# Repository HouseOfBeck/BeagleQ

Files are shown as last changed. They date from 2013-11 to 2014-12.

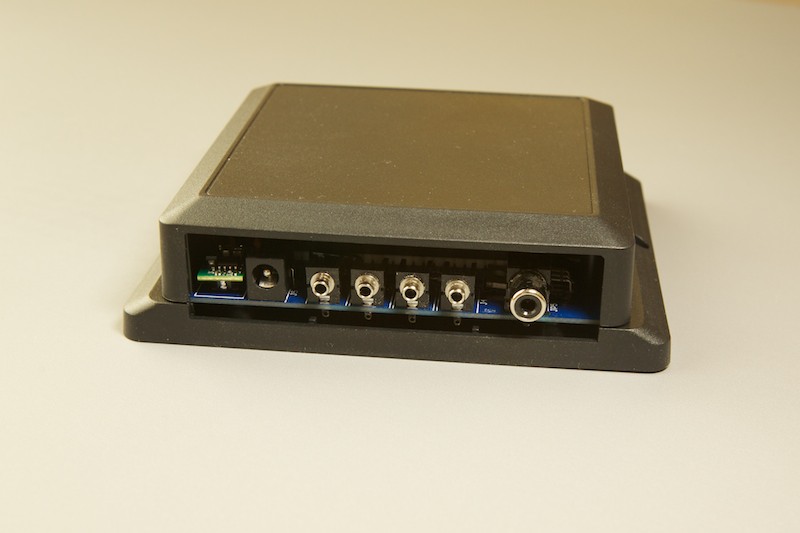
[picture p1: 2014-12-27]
images/beagleq-6.jpg

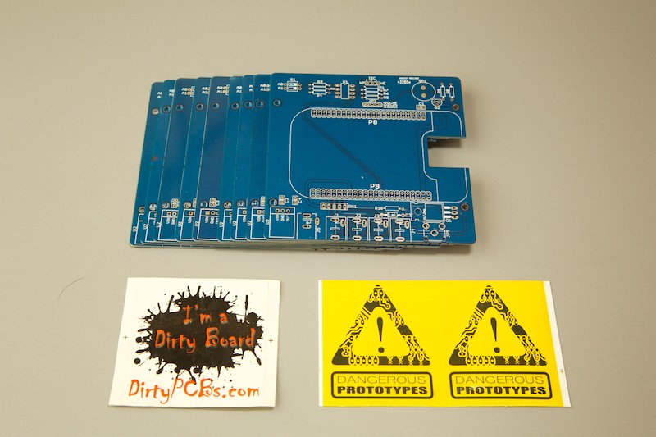
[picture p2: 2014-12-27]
images/beagleq-1.jpg

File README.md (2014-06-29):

BeagleQ bbq controller based on the beaglebone black platform.

Big changes for new Version 3.  New Version 3 board. Built in DC power converter. New form factor to fit off the shelf case.

The BeagleQ is a wifi enabled wireless intelligent bbq smoker controller. This device is designed to control a fan connected to the smoker's input vent/damper. Using a temperature probe placed in the pit the controller can read the pit temperature and then adjust the fan speed to act as a bellows to cause the coals to heat up and raise the pit temperature. The fan shuts down when the desired temperature is reached. By continually monitoring the temperature and adjusting the fan speed the controller can insure a smooth low and slow cook.

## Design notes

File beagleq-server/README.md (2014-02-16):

My first cut at node.js server. It requires the websocket 'ws' module.

Still a bit rough around the edges but I wanted to get something out.

It has a simulator mode where it will read the input file "cook.log" to use as input
temperatures. I use this for testing the PID and other functions.

For real use run start it up first then pull up the web client.

./beagleq-server
Parsing probes.json
Found probe ... ET-73
0.0002284143823
0.0002373151289
1.249333734e-7
R8: 9960
R9: 9950
R10: 9920
R11: 9995
Server running on port: 8086

<now start client in web browser>

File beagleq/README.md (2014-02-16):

This is the beagleq client.

Copy this entire directory into /usr/share/bone101/

Next, make sure the server is running.

then load the page in a web browser

http://your.beagle.address/beagleq/

If everything is working correctly you will see a connect message in the status pane.
Then temperatures will start appearing in the temperature pane and the gauges will 
indicate the temps. On the "chart" tab a plot will begin to appear.

The "test" tab is my play area. It will eventually go away.

The "about" tab will have the correct information for your beaglebone. The cape
eeprom data is static and not yet dynamic. It's on my list to fix.

Anyone with web frontend development skills is encouraged to help out.
In particular, I want to eliminate the google gauges in favor of something
like Highcharts so that the it can run without an internet connection.

Also, I need to add more tabs to tune the PID and manage output files.

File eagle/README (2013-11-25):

I've had a batch of these boards build at OSH Park and they work fine.
There's one minor issue. One mounting hole on the headphone/RCA jacks is a wee bit to small.
A little touch of the dremel on the pin and it fits in just fine.

Functionally I'm happy with this board and will use it as the basis for my
software developement.

You can order these boards from OSH Park here

http://www.oshpark.com/shared_projects/zo1bDKMN

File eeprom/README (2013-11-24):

This directory contains all the files needed to setup the eeprom on the
cape and the device tree overlays on the BBB.

These are the get started quick instructions. Details on customizing these
files will come later.

Write the eeprom image

1) Make sure the WP/WE jumper is in the WE position
2) The A0/A1 jumpers determine the cape i2c bus address. The two jumpers give you a range 
   from 0-3. The A2 address is fixed in hardware. Using the value set using the 
   A0/A1 jumpers plus 4 (ie 54-57) you can write the eeprom image using this command

   cat beagleq-cape-2.0.eeprom > /sys/bus/i2c/drivers/at24/1-005x/eeprom 

   If you want to check that it worked you can do a 

   cat /sys/devices/bone_capemgr.*/slots

3) Install the device tree overlay

   cp BeagleQ-02-00A0.dtbo /lib/firmware/. 

4) Reboot the BBB and check that the cape is there

   root@bbb-w:~# cat /sys/devices/bone_capemgr.*/slots
   0: 54:P---L BeagleQ-Cape,00A0,HouseOfBeck,BeagleQ-02
   1: 55:PF--- 
   2: 56:PF--- 
   3: 57:PF--- 
   4: ff:P-O-L Bone-LT-eMMC-2G,00A0,Texas Instrument,BB-BONE-EMMC-2G
   5: ff:P-O-L Bone-Black-HDMI,00A0,Texas Instrument,BB-BONELT-HDMI

Write calibartion data to eeprom

1) Carefully measure the values of R8, R9, R10, R11 during construction of the cape.
2) Edit the write_calibartion.py program to include your measured values. My values
   for this line were R8=9960, R9=9950,R10=9920,R11=9995

   out_array = array('l', [9960,9950,9920,9995])
3) Now write those values to the eeprom. The program writes the values and then
   reads then back out to verify.

   root@bbb-w:~/firmware# python write_calibration.py 
   array('l', [9960, 9950, 9920, 9995])

4) Move the WP/WE enable jumper to WP

Now go to the demo directory and see it work.

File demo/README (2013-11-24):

This simple python code uses the Adafruit BBIO library. First install it on
your BBB using the instructions found here

http://learn.adafruit.com/setting-up-io-python-library-on-beaglebone-black

You can then run this demo to exercise all the functions on the cape.

root@bbb-w:~/checkout# python demo.py

Reading calibration data from eeprom ... 

9960
9950
9920
9995

Reading ADC pins ...

P9_33 P9_38 P9_37 P9_40

1782.0 8.0 2.0 1637.0
1785.0 0.0 1.0 1614.0
1785.0 1.0 5.0 1624.0
1785.0 1.0 6.0 1656.0
1783.0 3.0 4.0 1664.0
1782.0 2.0 1.0 1664.0
1782.0 2.0 0.0 1661.0
1783.0 3.0 4.0 1643.0
1784.0 1.0 1.0 1661.0
1783.0 0.0 0.0 1628.0

Setting up PWM 4kHz on P9_16...buzzer test
Tearing down... Done...buzzer test
Setting up PWM...
Fan...100% duty cycle
Fan...75% duty cycle
Fan...50% duty cycle
Fan...25% duty cycle
Stopping...
Tearing down...
Done

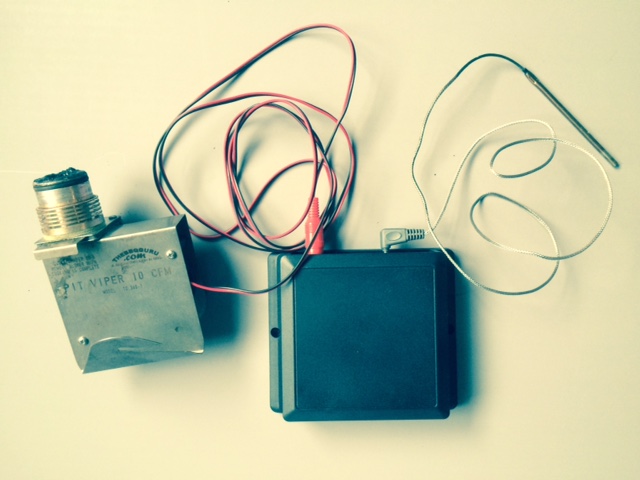
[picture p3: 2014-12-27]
images/beagleq-connect.jpg

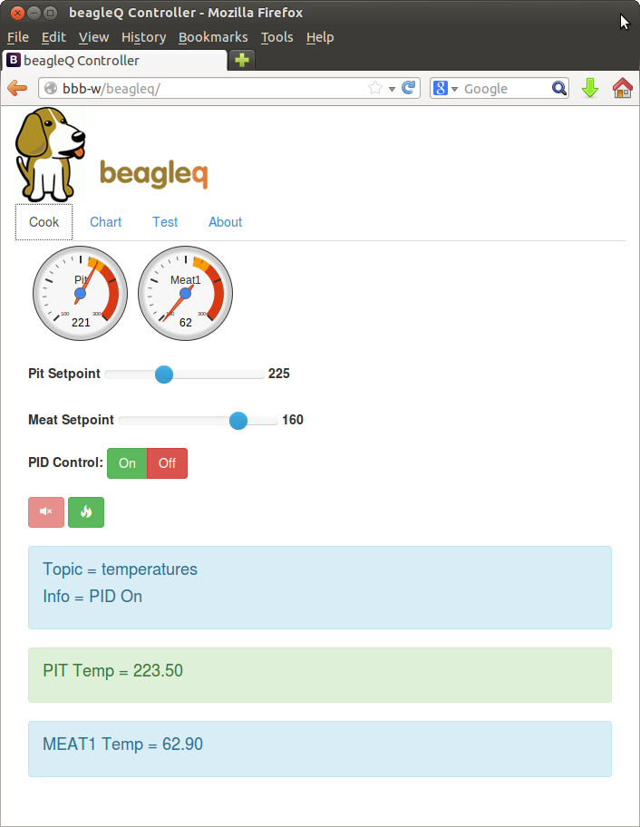
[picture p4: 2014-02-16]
images/beagleq-screen-cook.png

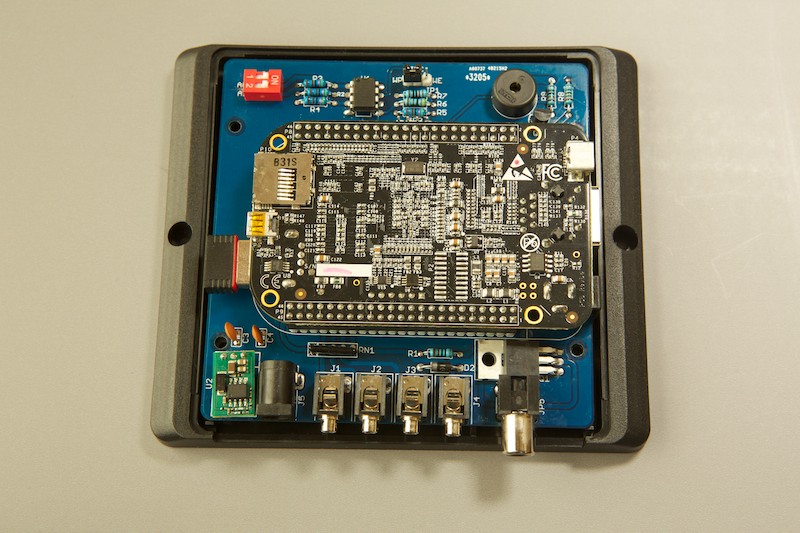
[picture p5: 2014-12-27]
images/beagleq-5.jpg

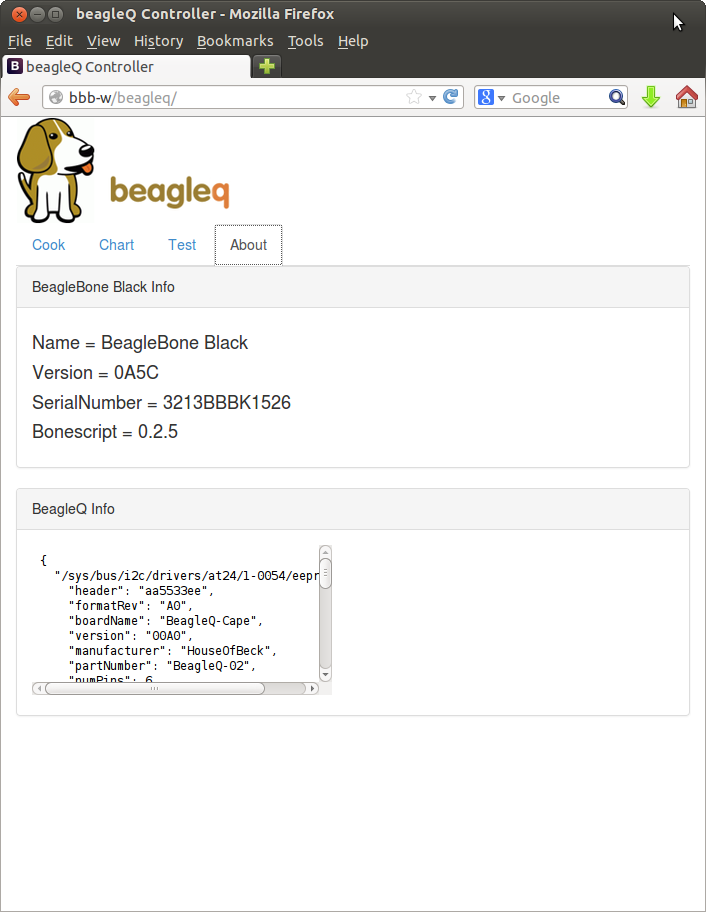
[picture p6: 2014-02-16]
images/beagleq-screen-about.png

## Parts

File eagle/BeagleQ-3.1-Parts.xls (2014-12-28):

Digi-Key Part Number | Manufacturer | Manufacturer Part Number | Customer Reference | Quantity 1 | Quantity 2 | Quantity 3 | Mfg Std Lead Time | Description | Comments | RoHS Status | Lead Free Status | REACH Status
PJRAN1X1U01X-ND | SWITCHCRAFT INC | PJRAN1X1U01X | JP5 FAN PLUG | 1 | 0 | 0 | 6 Weeks | CONN JACK 1POS R/A PHONO BLACK |  | RoHS Compliant | Lead free | Unaffected Dec-2012
445-2525-1-ND | TDK CORPORATION (VA) | PS1240P02BT | SP1 BUZZER | 1 | 0 | 0 | 12 Weeks | BUZZER PIEZO 4KHZ 12.2MM PC MNT | Alternate Packaging Exists | RoHS Compliant | Lead free | Unaffected Apr-2011
CP-2508N-ND | CUI INC | MJ-2508N | J1-J4 PROBE PLUGS | 4 | 0 | 0 | 11 Weeks | CONN AUDIO JACK 2.5MM MONO |  | RoHS Compliant | Lead free | Unaffected Oct-2010
CSC10KC-ND | VISHAY DALE | CSC05A0110K0GEK | RN1 | 1 | 0 | 0 | 22 Weeks | RES ARRAY 10K OHM 4 RES 5SIP |  | RoHS Compliant | Lead free | Unaffected Dec-2011
IRLB8721PBF-ND | INTERNATIONAL RECTIFIER | IRLB8721PBF | Q1 | 1 | 0 | 0 | 11 Weeks | MOSFET N-CH 30V 62A TO-220AB |  | RoHS Compliant | Lead free | Unaffected Dec-2013
BC2665CT-ND | VISHAY BC COMPONENTS (VA) | K104K10X7RF5UH5 | C1, C3, C4 | 3 | 0 | 0 | 6 Weeks | CAP CER 0.1UF 50V 10% RADIAL | Alternate Packaging Exists | RoHS Compliant | Lead free | Unaffected Jun-2011
641-1310-1-ND | COMCHIP TECHNOLOGY (VA) | 1N4001-G | D2 | 1 | 0 | 0 | 10 Weeks | DIODE GEN PURPOSE 50V 1A DO41 | Alternate Packaging Exists | RoHS Compliant | Lead free | Unaffected Dec-2013
24FC256-I/P-ND | MICROCHIP TECHNOLOGY | 24FC256-I/P | U1 EEPROM | 1 | 0 | 0 | 14 Weeks | IC EEPROM 256KBIT 1MHZ 8DIP |  | RoHS Compliant | Lead free | Unaffected Dec-2013
1.00KXBK-ND | YAGEO | MFR-25FBF52-1K | R1, R8, R9 | 3 | 0 | 0 | 14 Weeks | RES 1K OHM 1/4W 1% AXIAL | Alternate Packaging Exists | RoHS Compliant | Lead free | Unaffected Jun-2011
S4.7KCACT-ND | STACKPOLE ELECTRONICS INC (VA) | RNMF14FTC4K70 | R2-R6 | 5 | 0 | 0 | 12 Weeks | RES 4.7K OHM 1/4W 1% AXIAL | Alternate Packaging Exists | RoHS Compliant | Lead free | Unaffected Jun-2014
CP-102A-ND | CUI INC | PJ-102A | J5 POWER PLUG | 1 | 0 | 0 | 11 Weeks | CONN JACK POWER 2.1MM PCB |  | RoHS Compliant | Lead free | Unaffected Oct-2010
952-2330-ND | HARWIN INC | M20-9763646 | HEADER, DOUBLE | 2 | 0 | 0 | 8 Weeks | 2X36 POS DIL VERT PIN HDR |  | RoHS Compliant | Lead free | Unaffected Jun-2014
929400E-01-36-ND | 3M | 929400-01-36-RK | HEADER, SINGLE ROW | 1 | 0 | 0 | 2 Weeks | CONN HEADER .100 SNGL STR 36POS |  | RoHS Compliant | Lead free | Not Available
PN2222ATFCT-ND | FAIRCHILD SEMICONDUCTOR (VA) | PN2222ATF | Q2 SPEAKER TRANSISTOR | 1 | 0 | 0 | 7 Weeks | TRANS NPN 40V 1A TO-92 | Alternate Packaging Exists | RoHS Compliant | Lead free | Unaffected Dec-2013
811-2692-ND | MURATA POWER SOLUTIONS INC | OKI-78SR-5/1.5-W36H-C | DC-DC CONVERTER | 1 | 0 | 0 | 10 Weeks | DC/DC CONVERTER 5V 8W |  | RoHS Compliant | Lead free | Not Available
RNF14FTD10K0CT-ND | STACKPOLE ELECTRONICS INC (VA) | RNF14FTD10K0 | R7 | 1 | 0 | 0 | 12 Weeks | RES 10K OHM 1/4W 1% AXIAL | Alternate Packaging Exists | RoHS Compliant | Lead free | Unaffected Jun-2014
CT2082-ND | CTS ELECTROCOMPONENTS | 208-2 | S1 | 1 | 0 | 0 | 5 Weeks | SWITCH TIN CONT 2 SEC 50V |  | RoHS Compliant | Lead free | Unaffected Jul-2011

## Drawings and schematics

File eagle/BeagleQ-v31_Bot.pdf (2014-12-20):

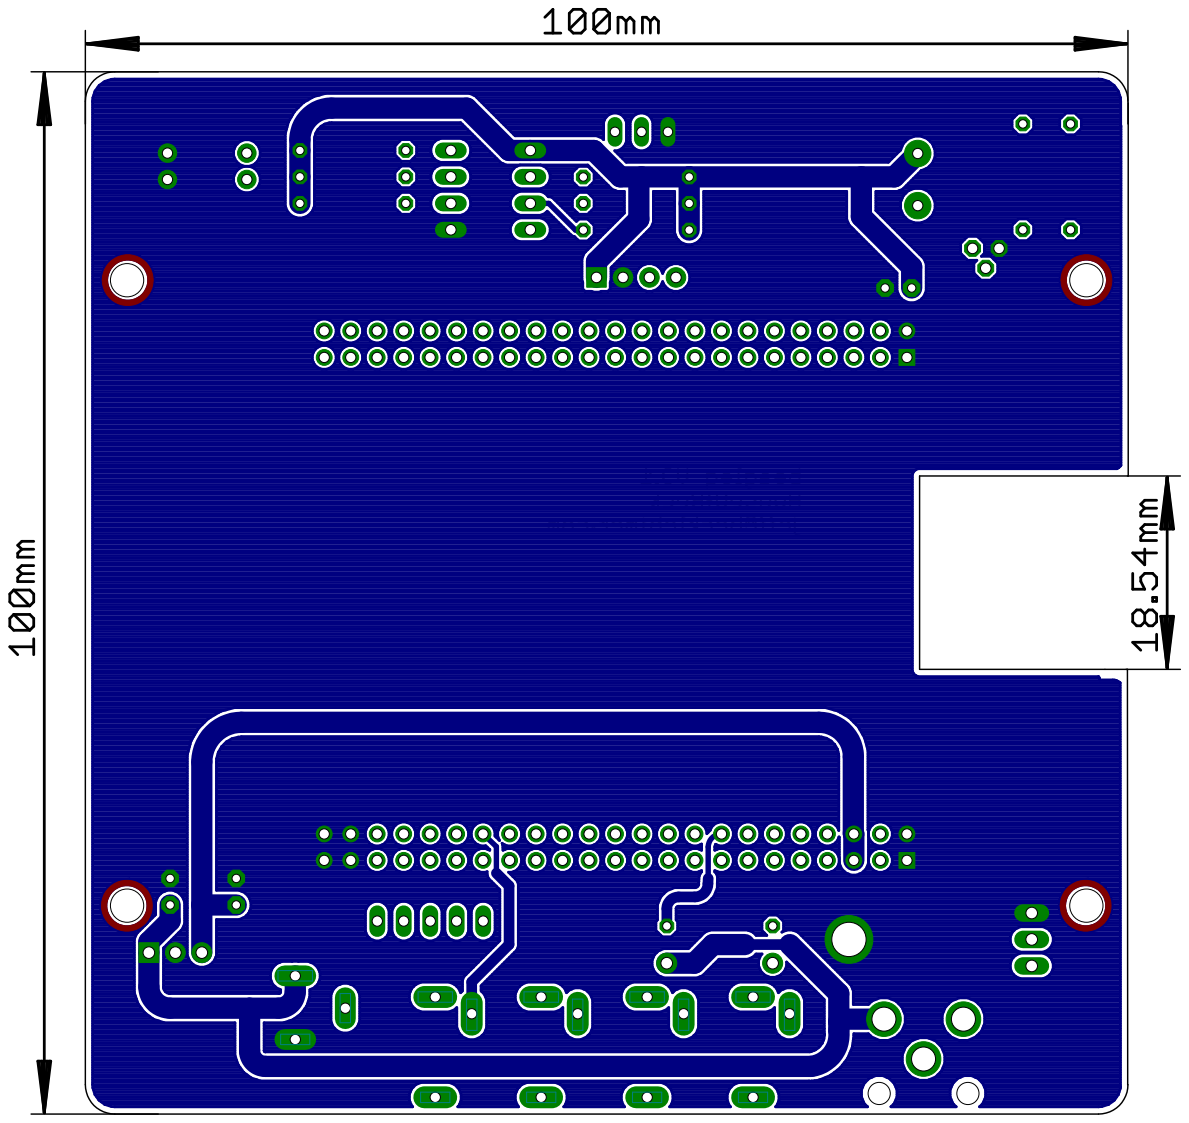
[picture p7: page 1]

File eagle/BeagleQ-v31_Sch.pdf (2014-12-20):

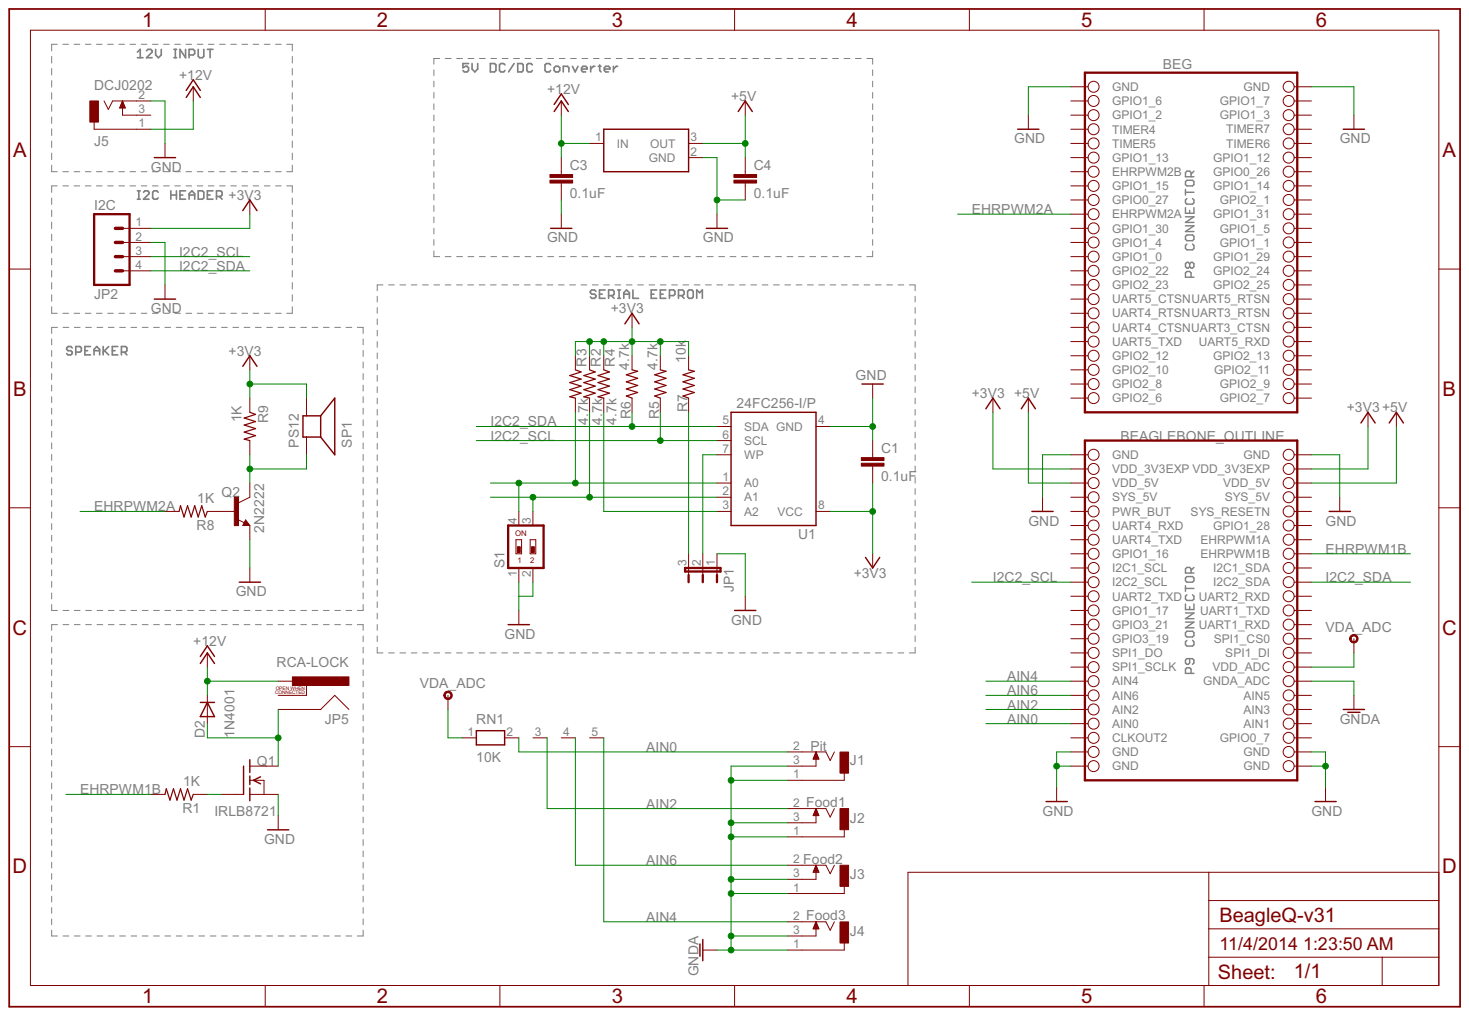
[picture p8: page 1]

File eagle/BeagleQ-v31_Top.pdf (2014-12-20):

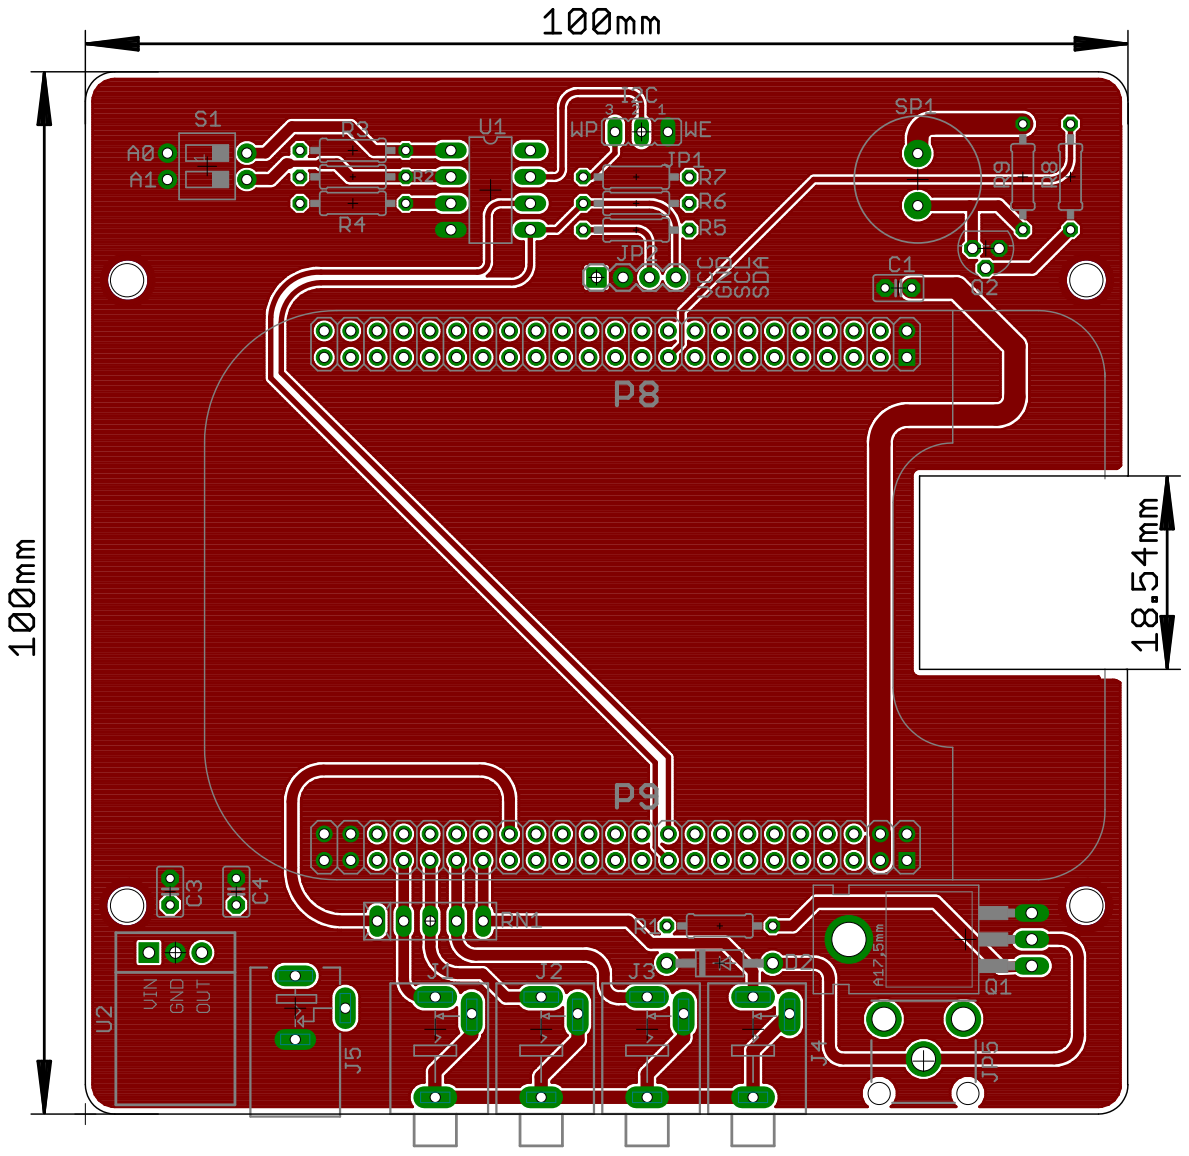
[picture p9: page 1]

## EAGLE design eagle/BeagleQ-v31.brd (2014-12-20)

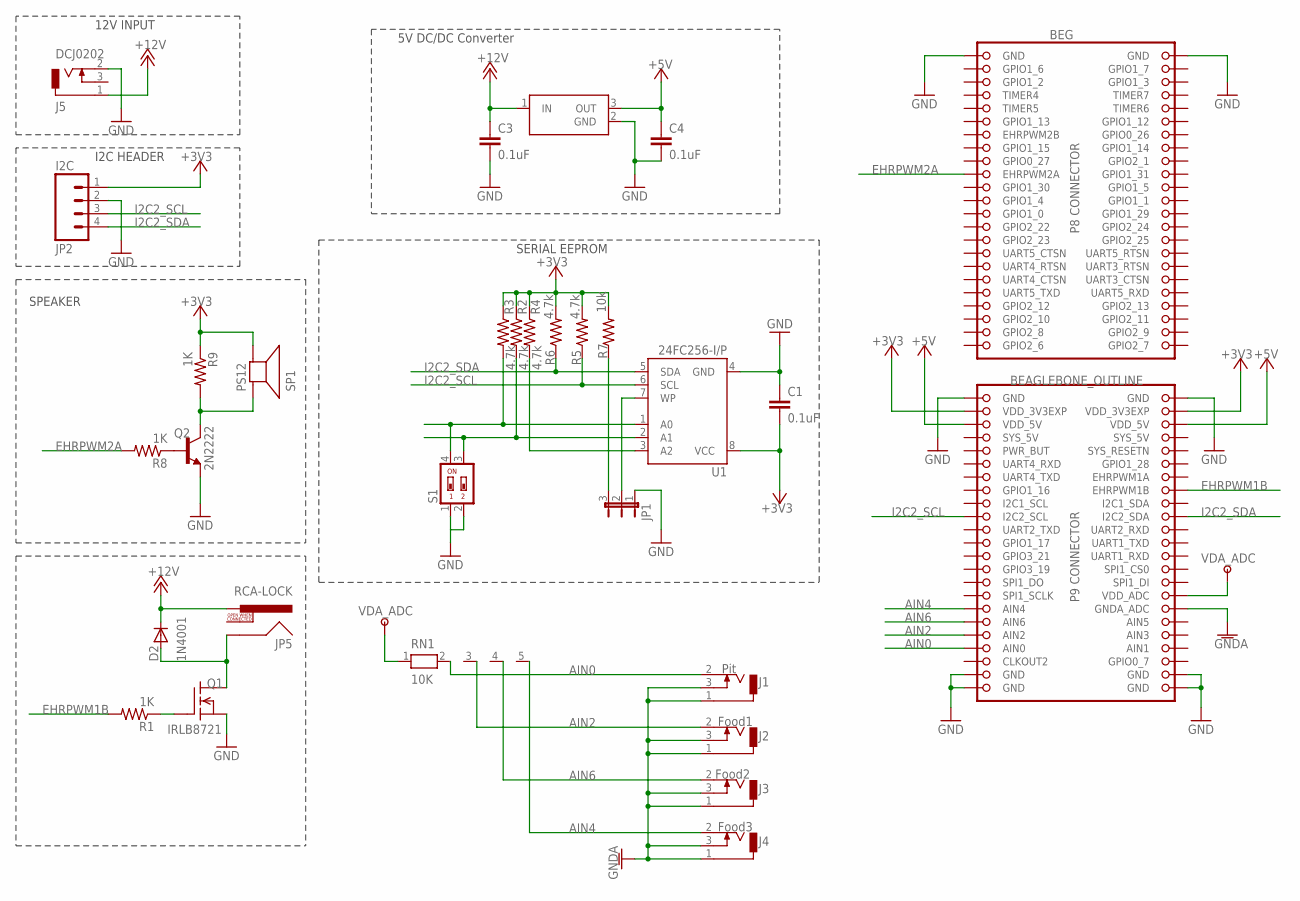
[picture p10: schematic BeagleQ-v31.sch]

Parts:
BEG: BEAGLEBONE_OUTLINE; BEAGLEBONE_SHIELD
C1, C3, C4: 0.1uF; C2.5-2
D2: 1N4001; DO41-10
J1: Pit; MJ-2508N
J2: Food1; MJ-2508N
J3: Food2; MJ-2508N
J4: Food3; MJ-2508N
J5: DCJ0202
JP1: WP; JP2
JP2: I2C; 1X04
JP5: RCA-LOCK; RCA_LOCK
Q1: IRLB8721; TO220
Q2: 2N2222; TO-92
R1, R8, R9: 1K; 0207/10
R2, R3, R4, R5, R6: 4.7k; 0207/10
R7: 10k; 0207/10
RN1: 10K; RN-5
S1: SWS002; SMS-002
SP1: PS12
U1: 24FC256-I/P; DIL08
U2: OKI-78SRHZNTL; OKI-78SR-HZNTL

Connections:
+3V3: BEG.49 (VDD_3V3EXP), BEG.50 (VDD_3V3EXP), C1.2, JP2.1, R2.1, R3.1, R4.1, R5.2, R6.2, R7.2, R9.1, SP1.P$2 (-), U1.8 (VCC)
+5V: BEG.51 (VDD_5V), BEG.52 (VDD_5V), C4.1, U2.3 (OUT)
+12V: C3.1, D2.C, J5.1, JP5.PIN, U2.1 (IN)
AIN0: BEG.85 (AIN0), J1.2, RN1.2
AIN2: BEG.83 (AIN2), J2.2, RN1.3
AIN4: BEG.79 (AIN4), J4.2, RN1.5
AIN6: BEG.81 (AIN6), J3.2, RN1.4
BLOWER_L: D2.A, JP5.SHELL, Q1.2 (D)
EHRPWM1B: BEG.62 (EHRPWM1B), R1.2
EHRPWM2A: BEG.19 (EHRPWM2A), R8.2
GND: BEG.1 (GND), BEG.2 (GND), BEG.47 (GND), BEG.48 (GND), BEG.89 (GND), BEG.90 (GND), BEG.91 (GND), BEG.92 (GND), C1.1, C3.2, C4.2, J5.2 (3), JP1.1, JP2.2, Q1.3 (S), Q1.4 (S), Q2.1 (E), S1.1, S1.2, U1.4 (GND), U2.2 (GND)
GNDA: BEG.80 (GNDA_ADC), J1.1, J1.3, J2.1, J2.3, J3.1, J3.3, J4.1, J4.3
I2C2_SCL: BEG.65 (I2C2_SCL), JP2.3, R5.1, U1.6 (SCL)
I2C2_SDA: BEG.66 (I2C2_SDA), JP2.4, R6.1, U1.5 (SDA)
unnamed: R2.2, S1.3, U1.2 (A1)
unnamed: R3.2, S1.4, U1.1 (A0)
unnamed: JP1.2, U1.7 (WP)
unnamed: Q1.1 (G), R1.1
unnamed: JP1.3, R7.1
unnamed: R4.2, U1.3 (A2)
unnamed: Q2.2 (B), R8.1
unnamed: Q2.3 (C), R9.2, SP1.P$1 (+)
SYS_5V: BEG.53 (SYS_5V)
VDA_ADC: BEG.78 (VDD_ADC), RN1.1

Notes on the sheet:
12V INPUT
I2C HEADER
SERIAL EEPROM
5V DC/DC Converter
SPEAKER

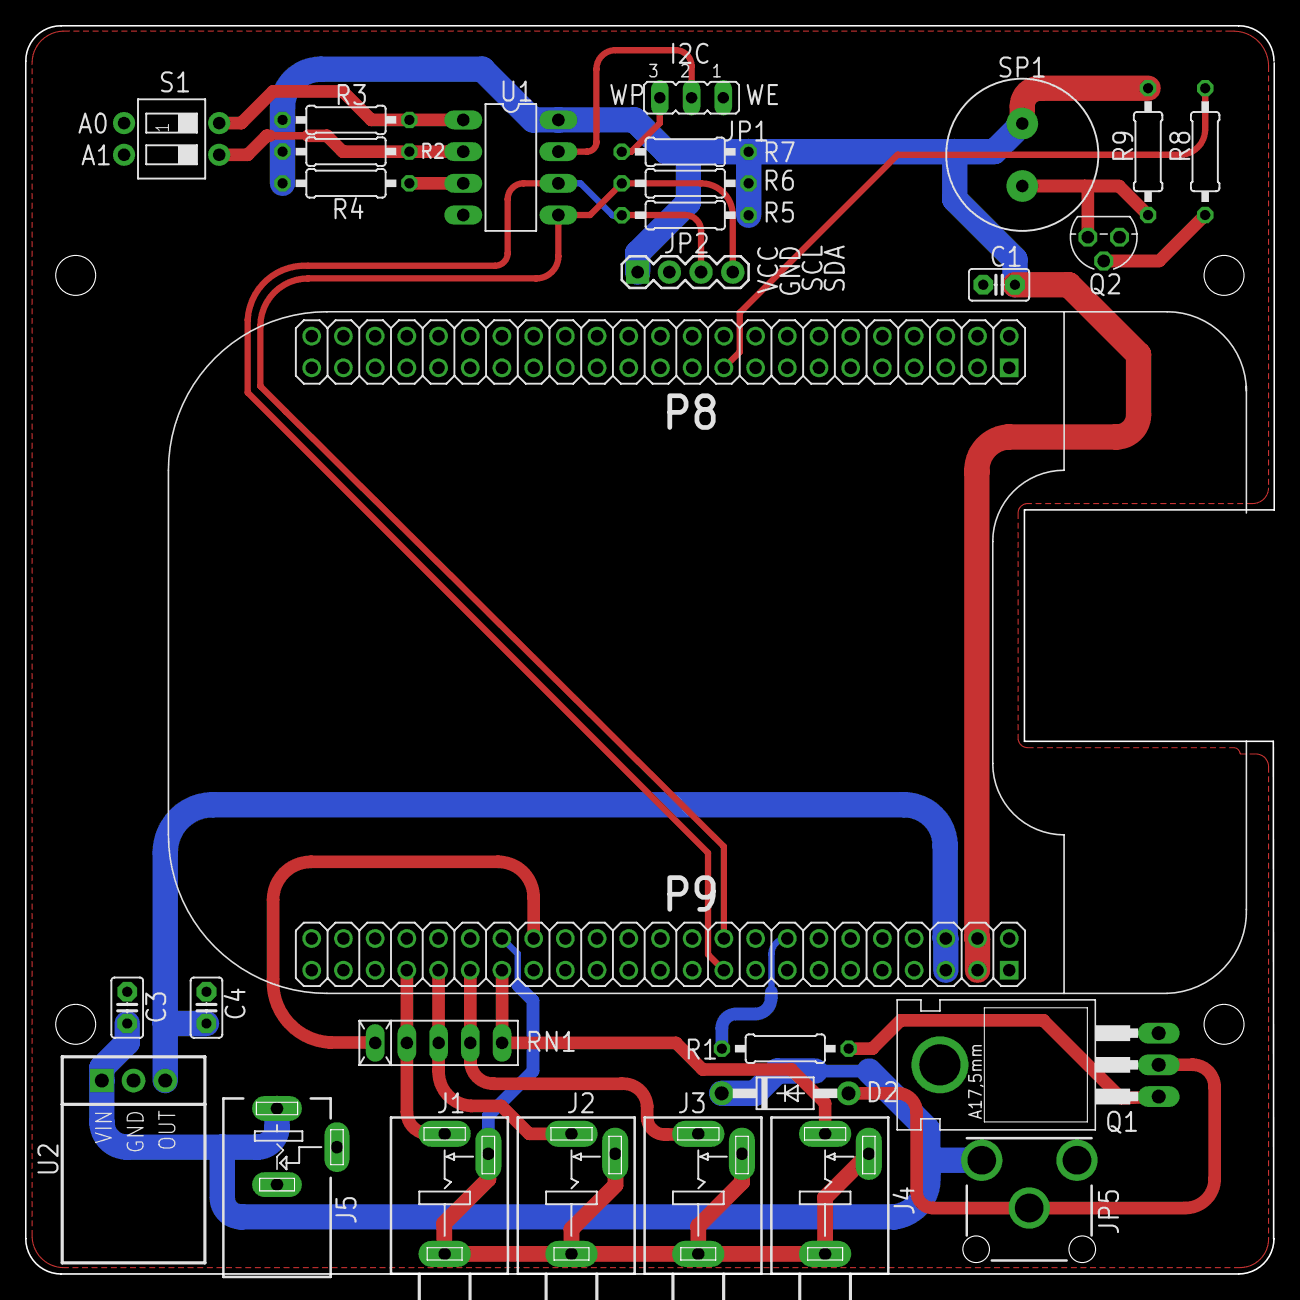
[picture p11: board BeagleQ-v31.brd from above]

Board: 2 copper layers, 100.0 x 100.0 mm, 29 parts (0 on the bottom side), 23 nets.

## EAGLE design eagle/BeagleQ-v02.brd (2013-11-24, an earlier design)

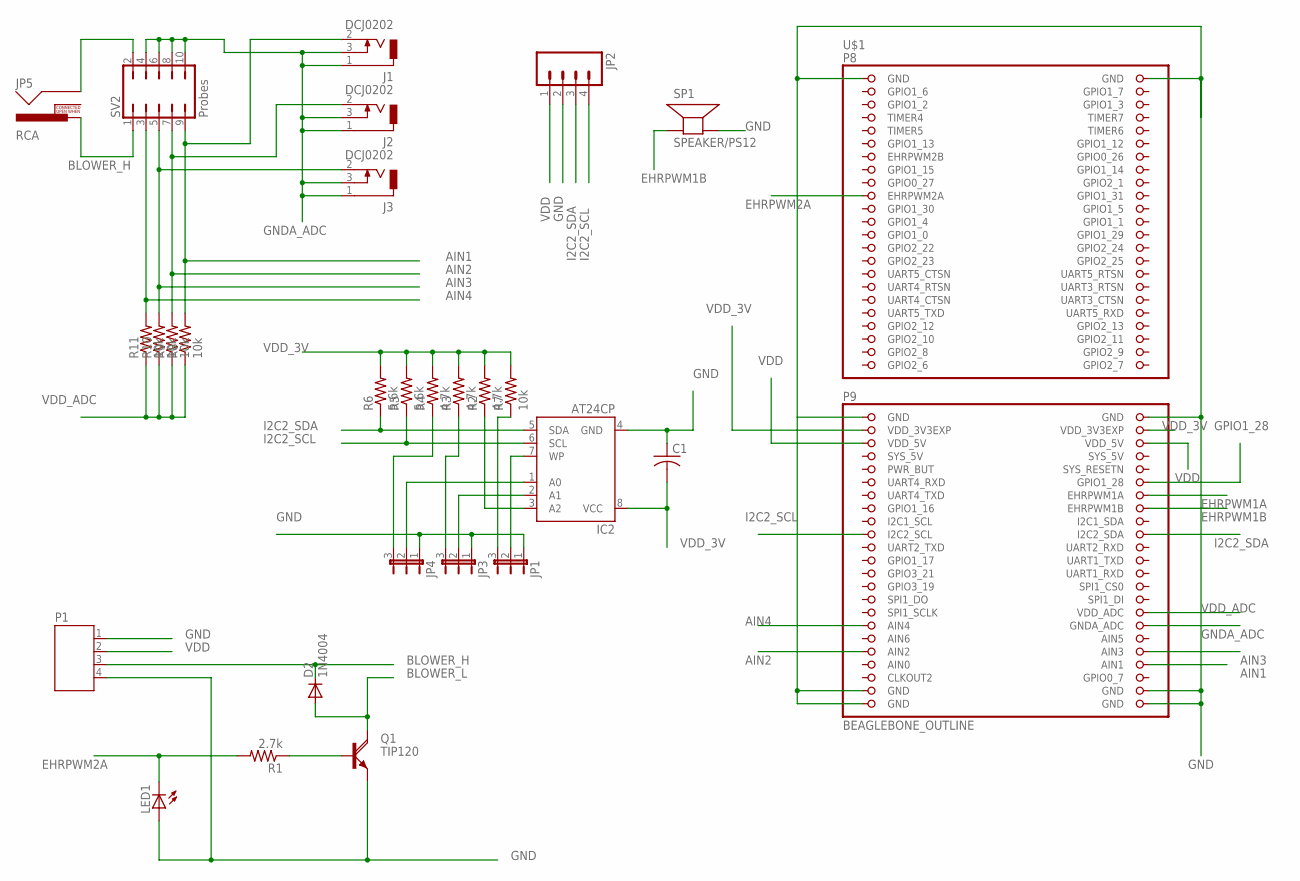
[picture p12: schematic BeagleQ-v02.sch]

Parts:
C1: C-US025-025X050; C025-025X050
D2: 1N4004; DO41-10
IC2: AT24CP; DIL08
J1, J2, J3: DCJ0202
JP1, JP3, JP4: JP2E; JP2
JP2: M04PTH; 1X04
JP5: RCA
LED1: LED3MM
P1: JST-PH4
Q1: TIP120; TO220AH
R1: 2.7k; 0207/10
R2, R3, R4: 4.7k; 0207/10
R5, R6: 5.6k; 0207/10
R7, R8, R9, R10, R11: 10k; 0207/10
SP1: SPEAKER/PS12; PS12
SV2: Probes; JP5Q
U$1: BEAGLEBONE_OUTLINE; BEAGLEBONE_SHIELD

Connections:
AIN0: U$1.85 (AIN0)
AIN1: J1.2, R8.2, SV2.9, U$1.86 (AIN1)
AIN2: J2.2, R9.2, SV2.7, U$1.83 (AIN2)
AIN3: J3.2, R10.2, SV2.5, U$1.84 (AIN3)
AIN4: R11.2, SV2.3, U$1.79 (AIN4)
BLOWER_H: D2.C, JP5.PIN, P1.3, SV2.1
BLOWER_L: D2.A, JP5.SHELL, Q1.C, SV2.2
EHRPWM1A: U$1.60 (EHRPWM1A)
EHRPWM1B: SP1.P$1 (+), U$1.62 (EHRPWM1B)
EHRPWM2A: LED1.K (C), R1.2, U$1.19 (EHRPWM2A)
GND: C1.1, IC2.4 (GND), JP1.1, JP2.2, JP3.1, JP4.1, LED1.A, P1.1, P1.4, Q1.E, SP1.P$2 (-), U$1.1 (GND), U$1.2 (GND), U$1.47 (GND), U$1.48 (GND), U$1.89 (GND), U$1.90 (GND), U$1.91 (GND), U$1.92 (GND)
GNDA_ADC: J1.1, J1.3, J2.1, J2.3, J3.1, J3.3, SV2.4, SV2.6, SV2.8, SV2.10, U$1.80 (GNDA_ADC)
GPIO1_28: U$1.58 (GPIO1_28)
I2C2_SCL: IC2.6 (SCL), JP2.4, R5.1, U$1.65 (I2C2_SCL)
I2C2_SDA: IC2.5 (SDA), JP2.3, R6.1, U$1.66 (I2C2_SDA)
unnamed: IC2.2 (A1), JP3.2
unnamed: IC2.1 (A0), JP4.2
unnamed: IC2.7 (WP), JP1.2
unnamed: Q1.B, R1.1
unnamed: JP1.3, R7.1
unnamed: JP3.3, R3.1
unnamed: JP4.3, R4.1
unnamed: IC2.3 (A2), R2.1
SYS_5V: U$1.53 (SYS_5V)
VDD: JP2.1, P1.2, U$1.51 (VDD_5V), U$1.52 (VDD_5V)
VDD_3V: C1.2, IC2.8 (VCC), R2.2, R3.2, R4.2, R5.2, R6.2, R7.2, U$1.49 (VDD_3V3EXP), U$1.50 (VDD_3V3EXP)
VDD_ADC: R8.1, R9.1, R10.1, R11.1, U$1.78 (VDD_ADC)

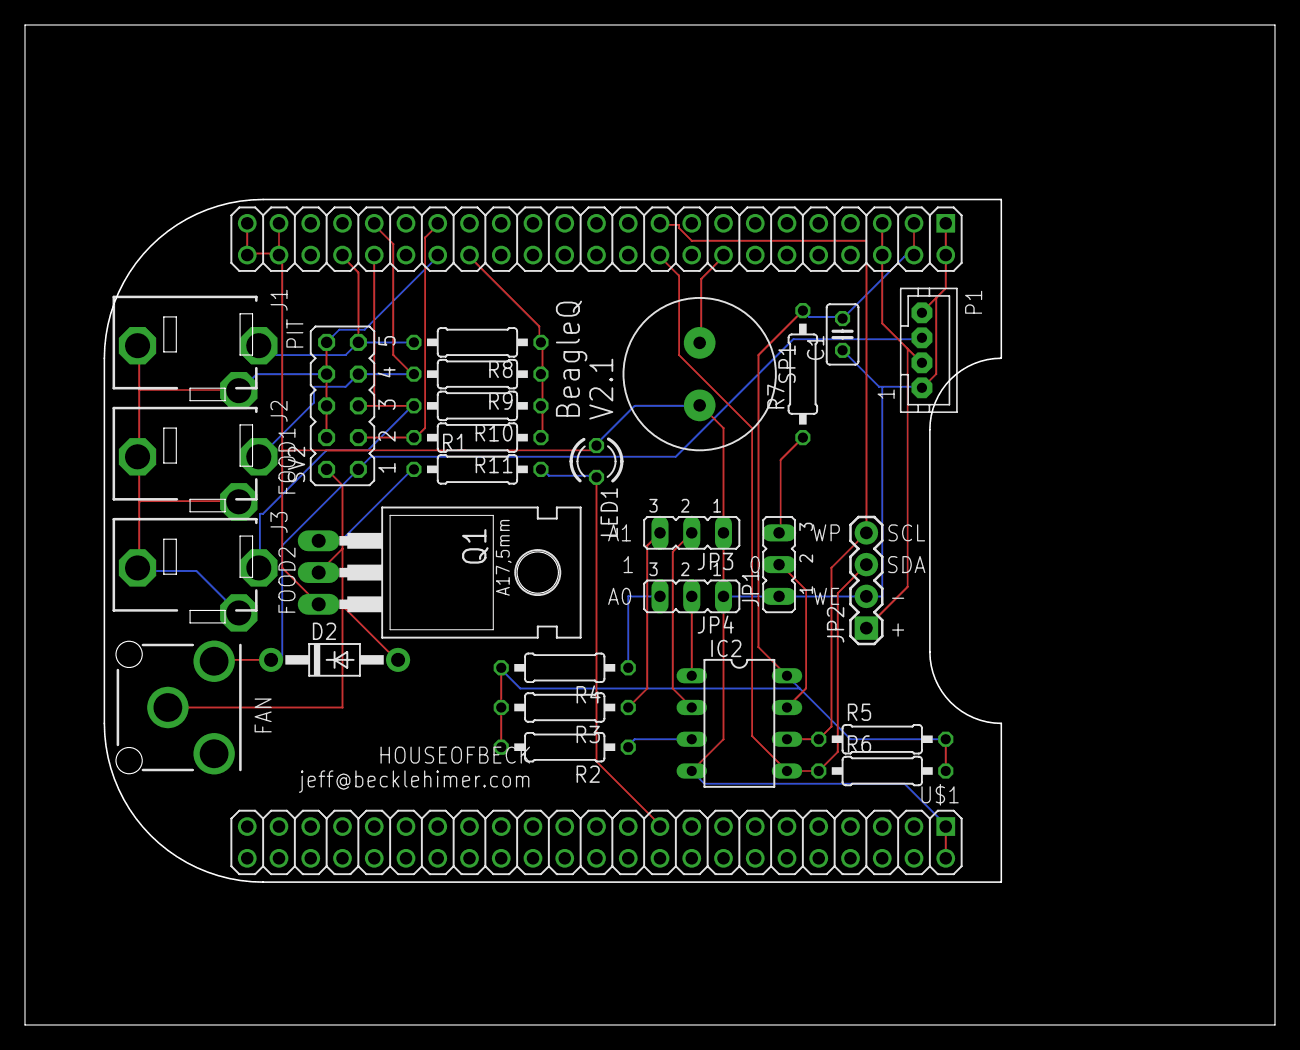
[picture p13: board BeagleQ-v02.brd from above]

Board: 2 copper layers, 100.0 x 80.0 mm, 28 parts (0 on the bottom side), 23 nets.

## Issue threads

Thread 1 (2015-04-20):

PCBs

ohararp, 2015-04-20:
HOB, any chance you have some Dirty PCBs still? I can go to OSHPARK or similar, but would rather take some boards off your hands if you have them.  Ryan

HouseOfBeck, 2015-04-21:
Yes, I have a few boards left. Send me your address and I'll mail a couple
out to you.

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

ohararp, 2015-04-21:
HoB, just one, maybe two?  I can paypal funds no problem.  I'm excited to try this out!

Ryan O'Hara, PhD
OHARARP LLC
2111 Explorer Trace
Hampton, VA 23665
937-430-8516
sales@ohararp.com

HouseOfBeck, 2015-04-21:
I just put two boards in an envelope. They'll go out in tomorrow's mail.

Let me know how it goes.

Jeff

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

ohararp, 2015-04-21:
Awesome, just placed Digikey order.  Super looking forward to putting this together!

ohararp, 2015-04-25:
Jeff, pcbs arrived and look great.  I sent some paypal funds to covers expenses.  Ryan

Closed 2015-04-25.

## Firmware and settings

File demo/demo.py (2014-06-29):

import Adafruit_BBIO.ADC as ADC
import Adafruit_BBIO.PWM as PWM
from array import array
import struct
import time

print "\nReading calibration data from eeprom ... \n"

eeprom = open('/sys/bus/i2c/drivers/at24/1-0054/eeprom', 'rb')
eeprom.seek(244)
in_array = array('l')
in_array.fromfile(eeprom,4)
eeprom.close()

for i in range(4):
	print in_array[i]

ADC.setup()
       
print "\nReading ADC pins ...\n"
print "P9_39 P9_37 P9_35 P9_33\n"

for i in range(10):
	raw1 = ADC.read_raw('P9_39')
	raw2 = ADC.read_raw('P9_37')
	raw3 = ADC.read_raw('P9_35')
	raw4 = ADC.read_raw('P9_33')
	print raw1, raw2, raw3, raw4
	time.sleep(1)
     

print
print "Setting up PWM 4kHz on P9_16...buzzer test"
pwm_pin = 'P8_19'
PWM.start(pwm_pin, 25, 4000)

PWM.set_duty_cycle(pwm_pin, 50)
time.sleep(2)

PWM.set_duty_cycle(pwm_pin, 0)

print "Tearing down...",
PWM.stop(pwm_pin)

PWM.cleanup()
print "Done...buzzer test"

pwm_pin = 'P9_16'

print "Setting up PWM..."
print "Fan...100% duty cycle"
PWM.start(pwm_pin, 100, 20000)

time.sleep(6)

print "Fan...75% duty cycle"
PWM.set_duty_cycle(pwm_pin, 75)
time.sleep(6)

print "Stopping..."
PWM.set_duty_cycle(pwm_pin, 0)

print "Tearing down..."
PWM.stop(pwm_pin)

PWM.cleanup()
print "Done"

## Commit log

2013-10-02 Eagle Files
    [BeagleQ-v02.brd, BeagleQ-v02.sch]
2013-11-24 Functioning hardware
    [BeagleQ-v02.brd, BeagleQ-v02.sch]
2014-02-16 more board pictures
2014-07-11 Added support for Adafruit i2c 7-segment display
2014-08-19 Major Cleanup
    [BeagleQ-v03.1.brd, BeagleQ-v03.1.sch]
2014-12-20 Minor Cleanup
    [BeagleQ-v31.brd, BeagleQ-v31.sch]
2014-12-28 Parts List
    [BeagleQ-3.1-Parts.xls]

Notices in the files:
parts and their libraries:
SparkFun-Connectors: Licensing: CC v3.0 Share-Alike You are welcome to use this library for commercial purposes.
